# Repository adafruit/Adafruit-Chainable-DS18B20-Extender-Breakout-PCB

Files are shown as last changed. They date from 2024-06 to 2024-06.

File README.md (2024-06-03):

## Adafruit Chainable DS18B20 Extender Breakout - STEMMA JST PH 2mm PCB

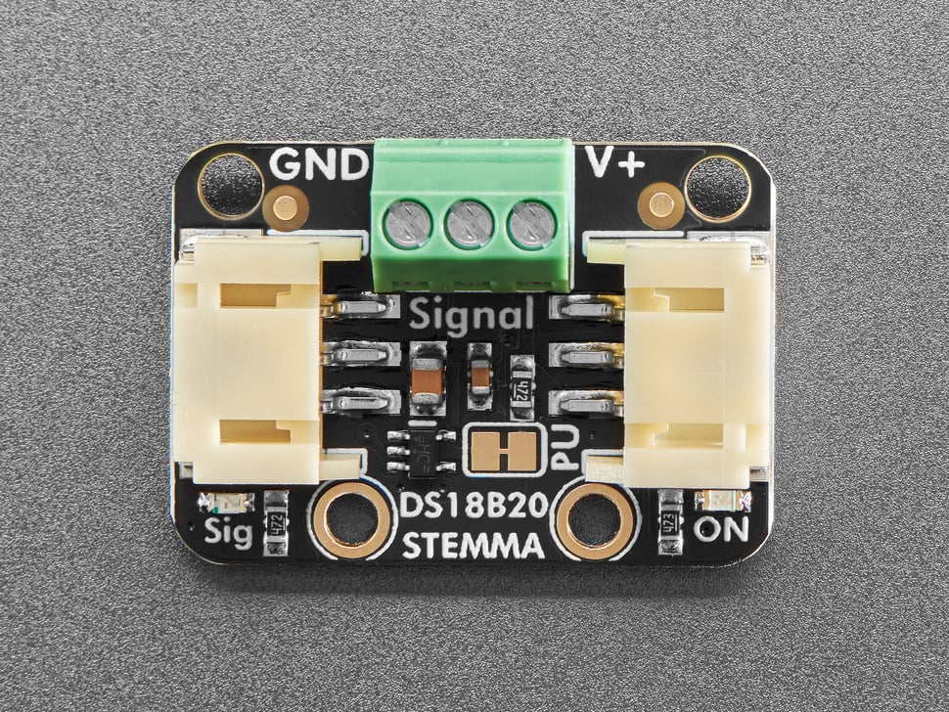
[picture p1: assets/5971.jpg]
<a href="http://www.adafruit.com/products/5971"><br/>
Click here to purchase one from the Adafruit shop</a>

PCB files for the Adafruit Chainable DS18B20 Extender Breakout - STEMMA JST PH 2mm. 

Format is EagleCAD schematic and board layout
* https://www.adafruit.com/product/5971

### Description

One of the perks of working at adafruit is you get to request hardware - and you'll probably get fast turnaround! One of our adafruit.io developers requested "an easy way to chain DS18B20 sensors for testing with adafruit.io's wippersnapper service" at 11:54am one Monday morning, and after a few back-and-forth's we came up with the Adafruit Chainable DS18B20 Extender Breakout. Bit of a mouth-full, but we're better engineers than marketers doncha-know.

While there is absolutely nothing stopping you from just wiring up DS18B20's directly to your microcontroller, these extender breakouts will make things just a lil bit easier. You can use JST 3-pin cables to chain the extenders, the soldered-on screw terminal blocks mean you can easily connect DS18B20's in TO-92 or cable style with just a screwdriver. 

Each extender has a 4.7K signal pullup on board that can be disabled by cutting a trace, and a buffered signal LED that will let you know when there's data transmission on the 1-Wire line. When the red LED blinks, you know that data is going over the 1-wire line.

Please Note: This board doesn't come with a DS18B20 sensor itself; it's just an adapter-helper. You supply the sensor + a JST PH-compatible 3-pin cable.

### License

Adafruit invests time and resources providing this open source design, please support Adafruit and open-source hardware by purchasing products from [Adafruit](https://www.adafruit.com)!

Designed by Limor Fried/Ladyada for Adafruit Industries.

Creative Commons Attribution/Share-Alike, all text above must be included in any redistribution. 
See license.txt for additional details.

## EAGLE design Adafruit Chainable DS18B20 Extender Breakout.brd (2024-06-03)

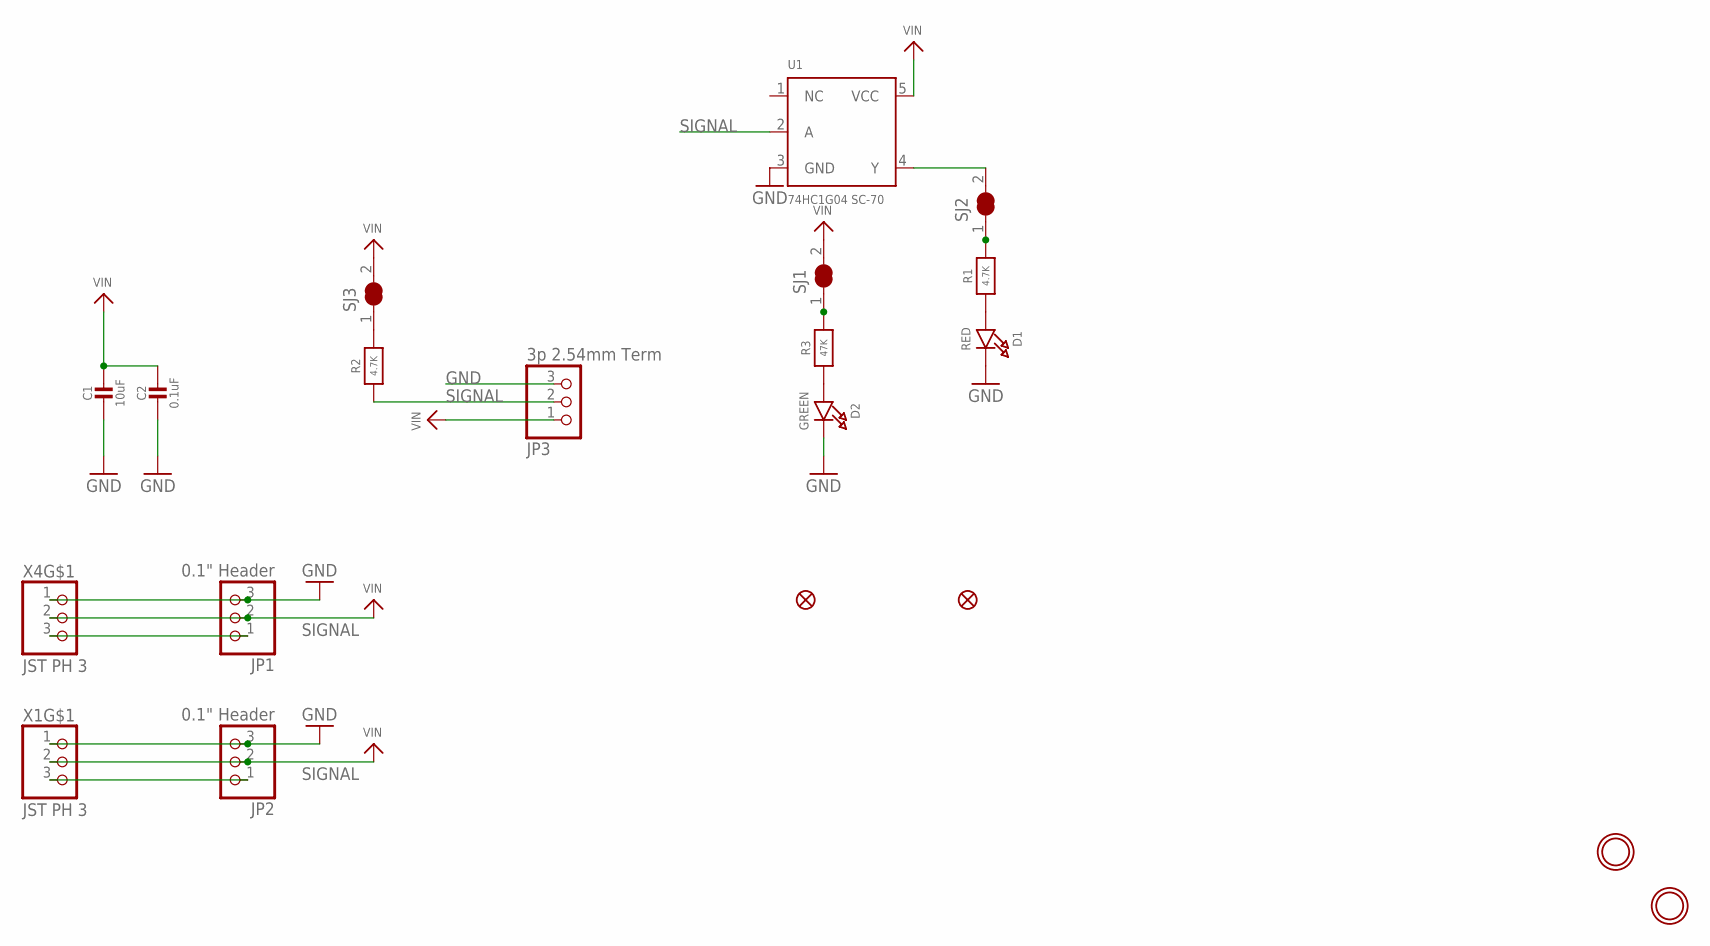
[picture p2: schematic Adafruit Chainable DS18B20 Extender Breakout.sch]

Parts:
C1: 10uF; 0805-NO
C2: 0.1uF; 0603-NO
D1: RED; CHIPLED_0603_NOOUTLINE
D2: GREEN; CHIPLED_0603_NOOUTLINE
FID2, FID3: FIDUCIAL_1MM
JP1, JP2: 0.1" Header; 1X03_OVAL
JP3: 3p 2.54mm Term; 1X03_2.54MMTERMINAL
R1, R2: 4.7K; 0603-NO
R3: 47K; 0603-NO
SJ1, SJ2, SJ3: SOLDERJUMPER_CLOSED; SOLDERJUMPER_CLOSEDWIRE
U1: 74HC1G04 SC-70; SC70-5
U$1, U$8: MOUNTINGHOLE2.0; MOUNTINGHOLE_2.0_PLATED
X1, X4: JST PH 3; JSTPH3

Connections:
GND: C1.2, C2.2, D1.C, D2.C, JP1.3, JP2.3, JP3.3, U1.3 (GND), X1.1, X4.1
unnamed: R3.2, SJ1.1
unnamed: D1.A, R1.1
unnamed: R1.2, SJ2.1
unnamed: R2.2, SJ3.1
unnamed: SJ2.2, U1.4 (Y)
unnamed: D2.A, R3.1
SIGNAL: JP1.1, JP2.1, JP3.2, R2.1, U1.2 (A), X1.3, X4.3
VIN: C1.1, C2.1, JP1.2, JP2.2, JP3.1, SJ1.2, SJ3.2, U1.5 (VCC), X1.2, X4.2

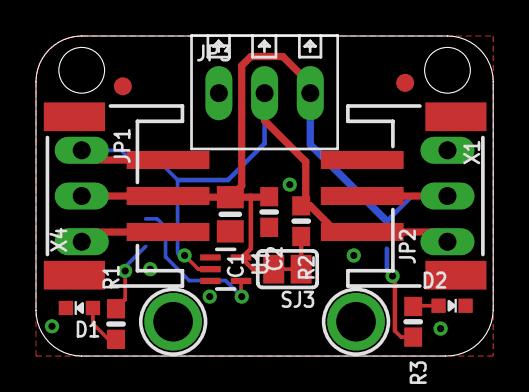
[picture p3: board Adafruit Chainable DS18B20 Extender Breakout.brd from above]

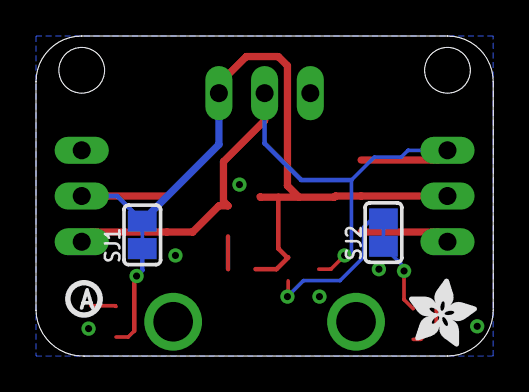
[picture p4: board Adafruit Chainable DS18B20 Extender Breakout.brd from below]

Board: 2 copper layers, 25.4 x 17.8 mm, 36 parts (11 on the bottom side), 9 nets.

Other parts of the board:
PLABEL0: PLABEL0
PLABEL1: PLABEL1
PLABEL13: PLABEL13
PLABEL14: PLABEL14
PLABEL15: PLABEL15
PLABEL16: PLABEL16
PLABEL17: PLABEL17
PLABEL18: PLABEL18
PLABEL19: PLABEL19
PLABEL20: PLABEL20
PLABEL21: PLABEL21
PLABEL22: PLABEL22
PLABEL24: PLABEL24
PLABEL25: PLABEL25
U$3: PCBFEAT-REV-040
U$12: ADAFRUIT_3.5MM

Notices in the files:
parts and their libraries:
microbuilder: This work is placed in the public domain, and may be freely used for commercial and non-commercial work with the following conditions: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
